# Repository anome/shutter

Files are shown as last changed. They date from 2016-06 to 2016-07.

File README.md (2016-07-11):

# SHUTTER

This repository contains all the files necessary to build your own radio shutter.
- The pcb folder contains the gerberfiles that you can send to any PCB factory.
- The laser folder contains the laser cutting files for 4 and 6 mm box.
- The code folder containsthe Arduino and PlatformIO projects to upload the code on the board

There is also an assembly guide explaining how to assemble all this.

## License

Those files are released under the CC-BY-NC license. More infos in the LICENSE.txt file.

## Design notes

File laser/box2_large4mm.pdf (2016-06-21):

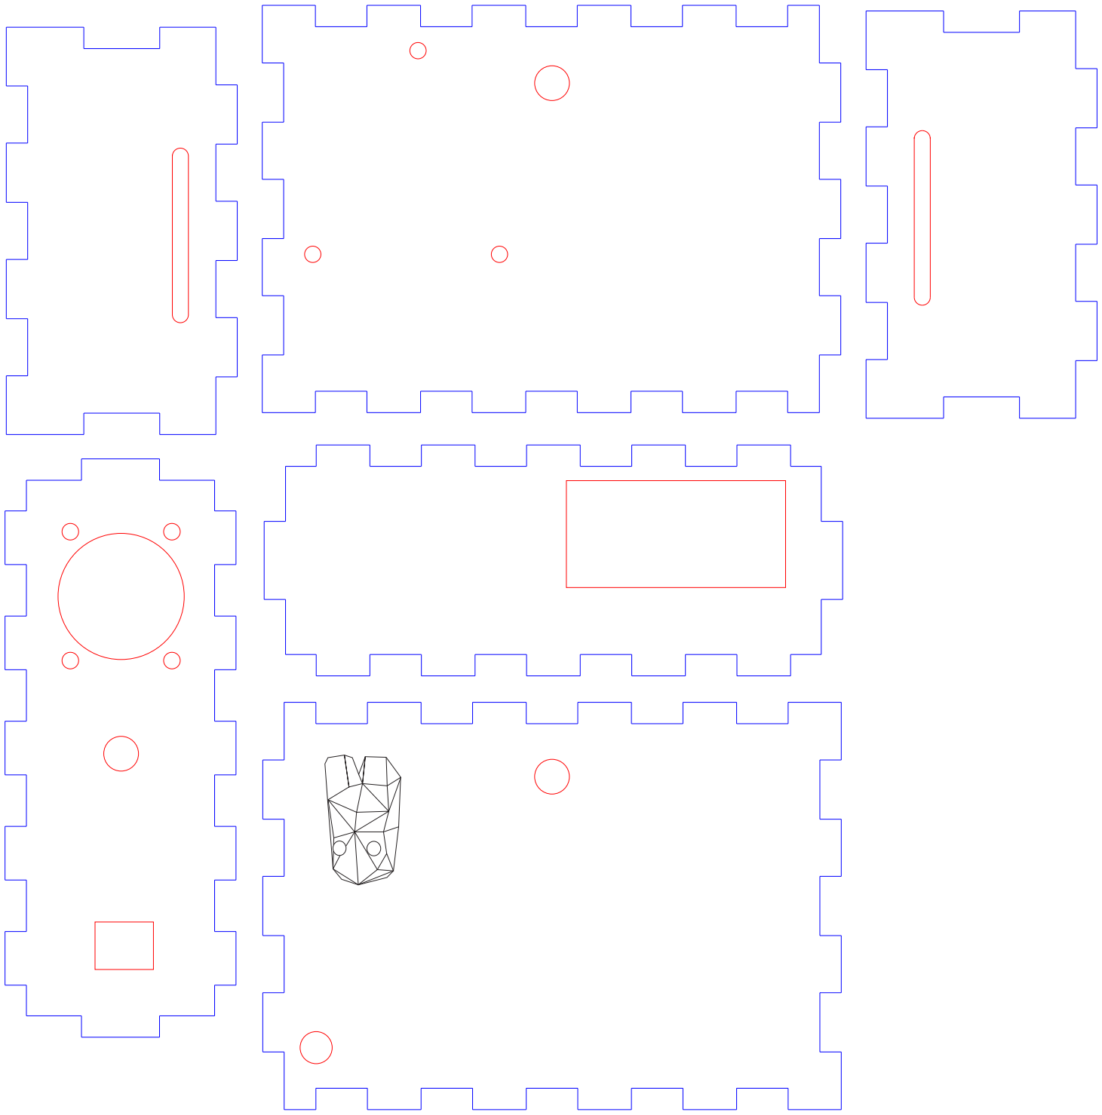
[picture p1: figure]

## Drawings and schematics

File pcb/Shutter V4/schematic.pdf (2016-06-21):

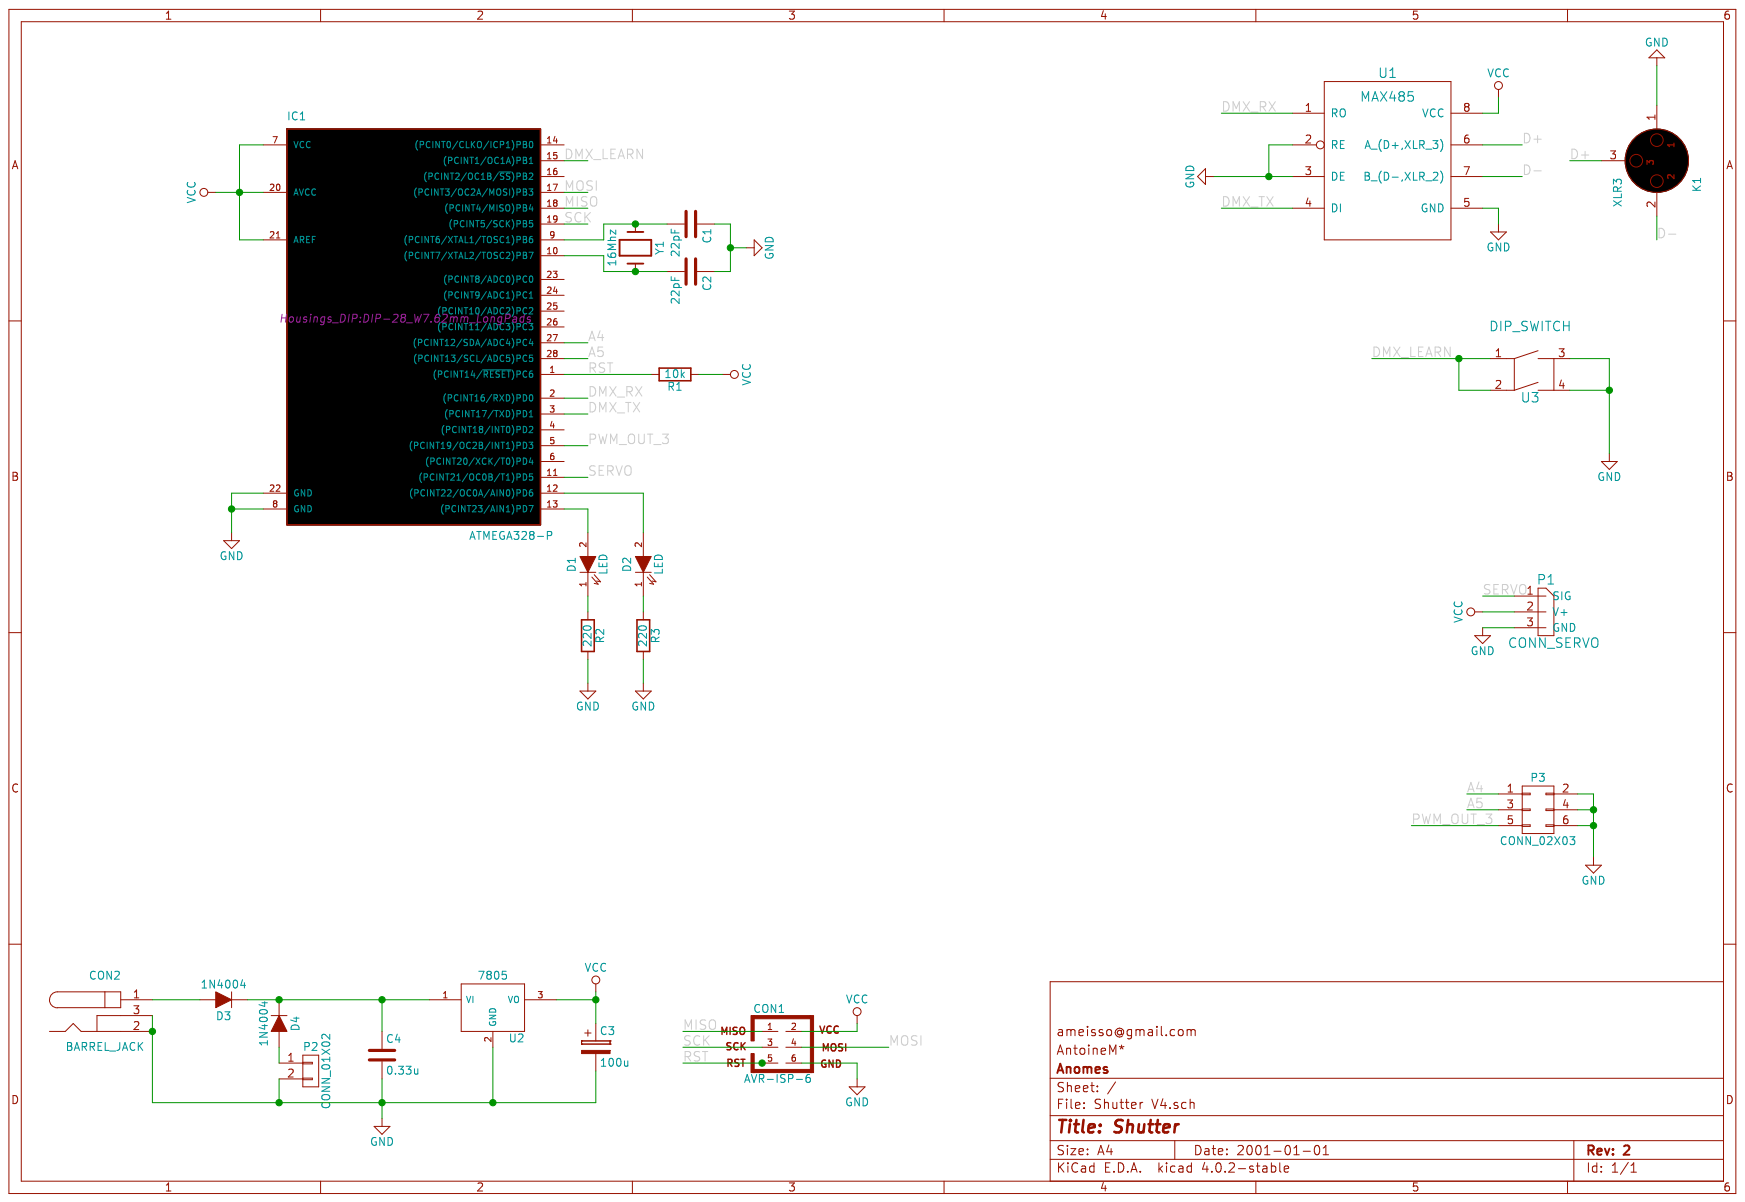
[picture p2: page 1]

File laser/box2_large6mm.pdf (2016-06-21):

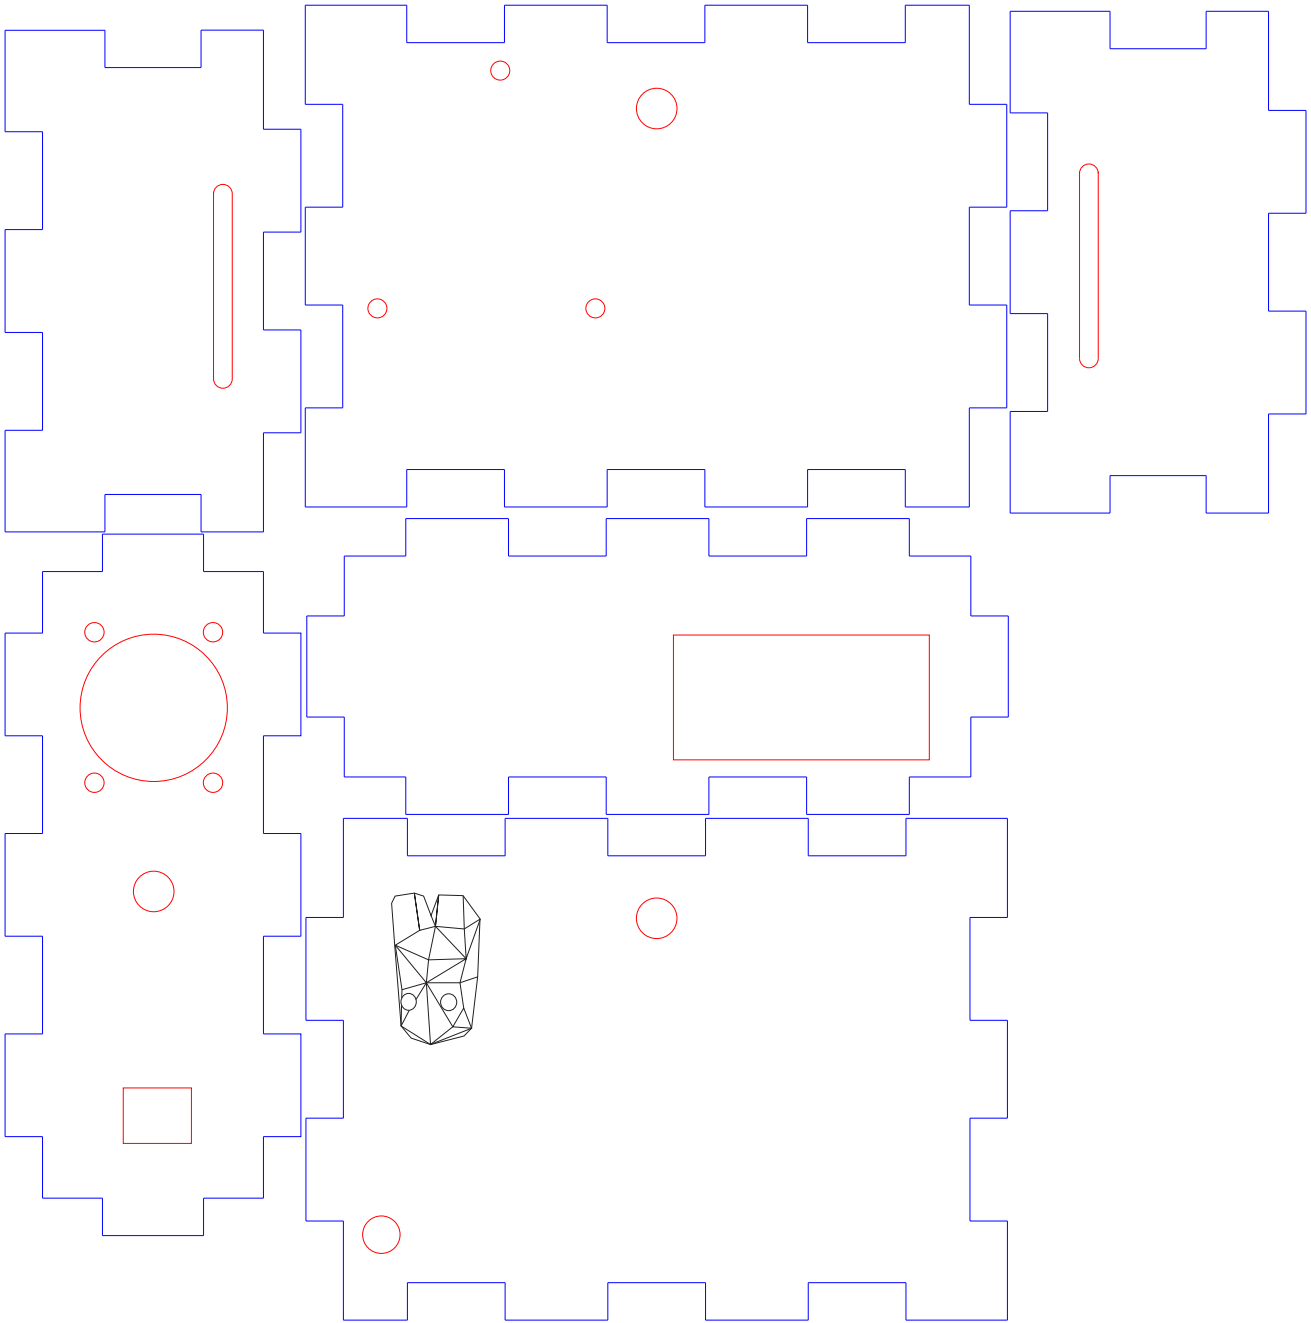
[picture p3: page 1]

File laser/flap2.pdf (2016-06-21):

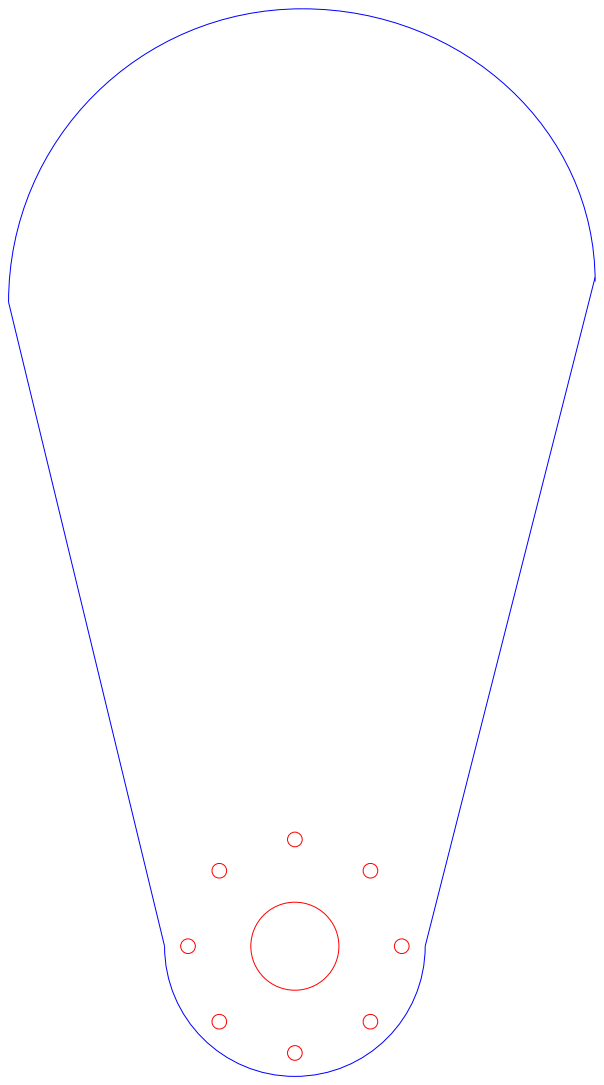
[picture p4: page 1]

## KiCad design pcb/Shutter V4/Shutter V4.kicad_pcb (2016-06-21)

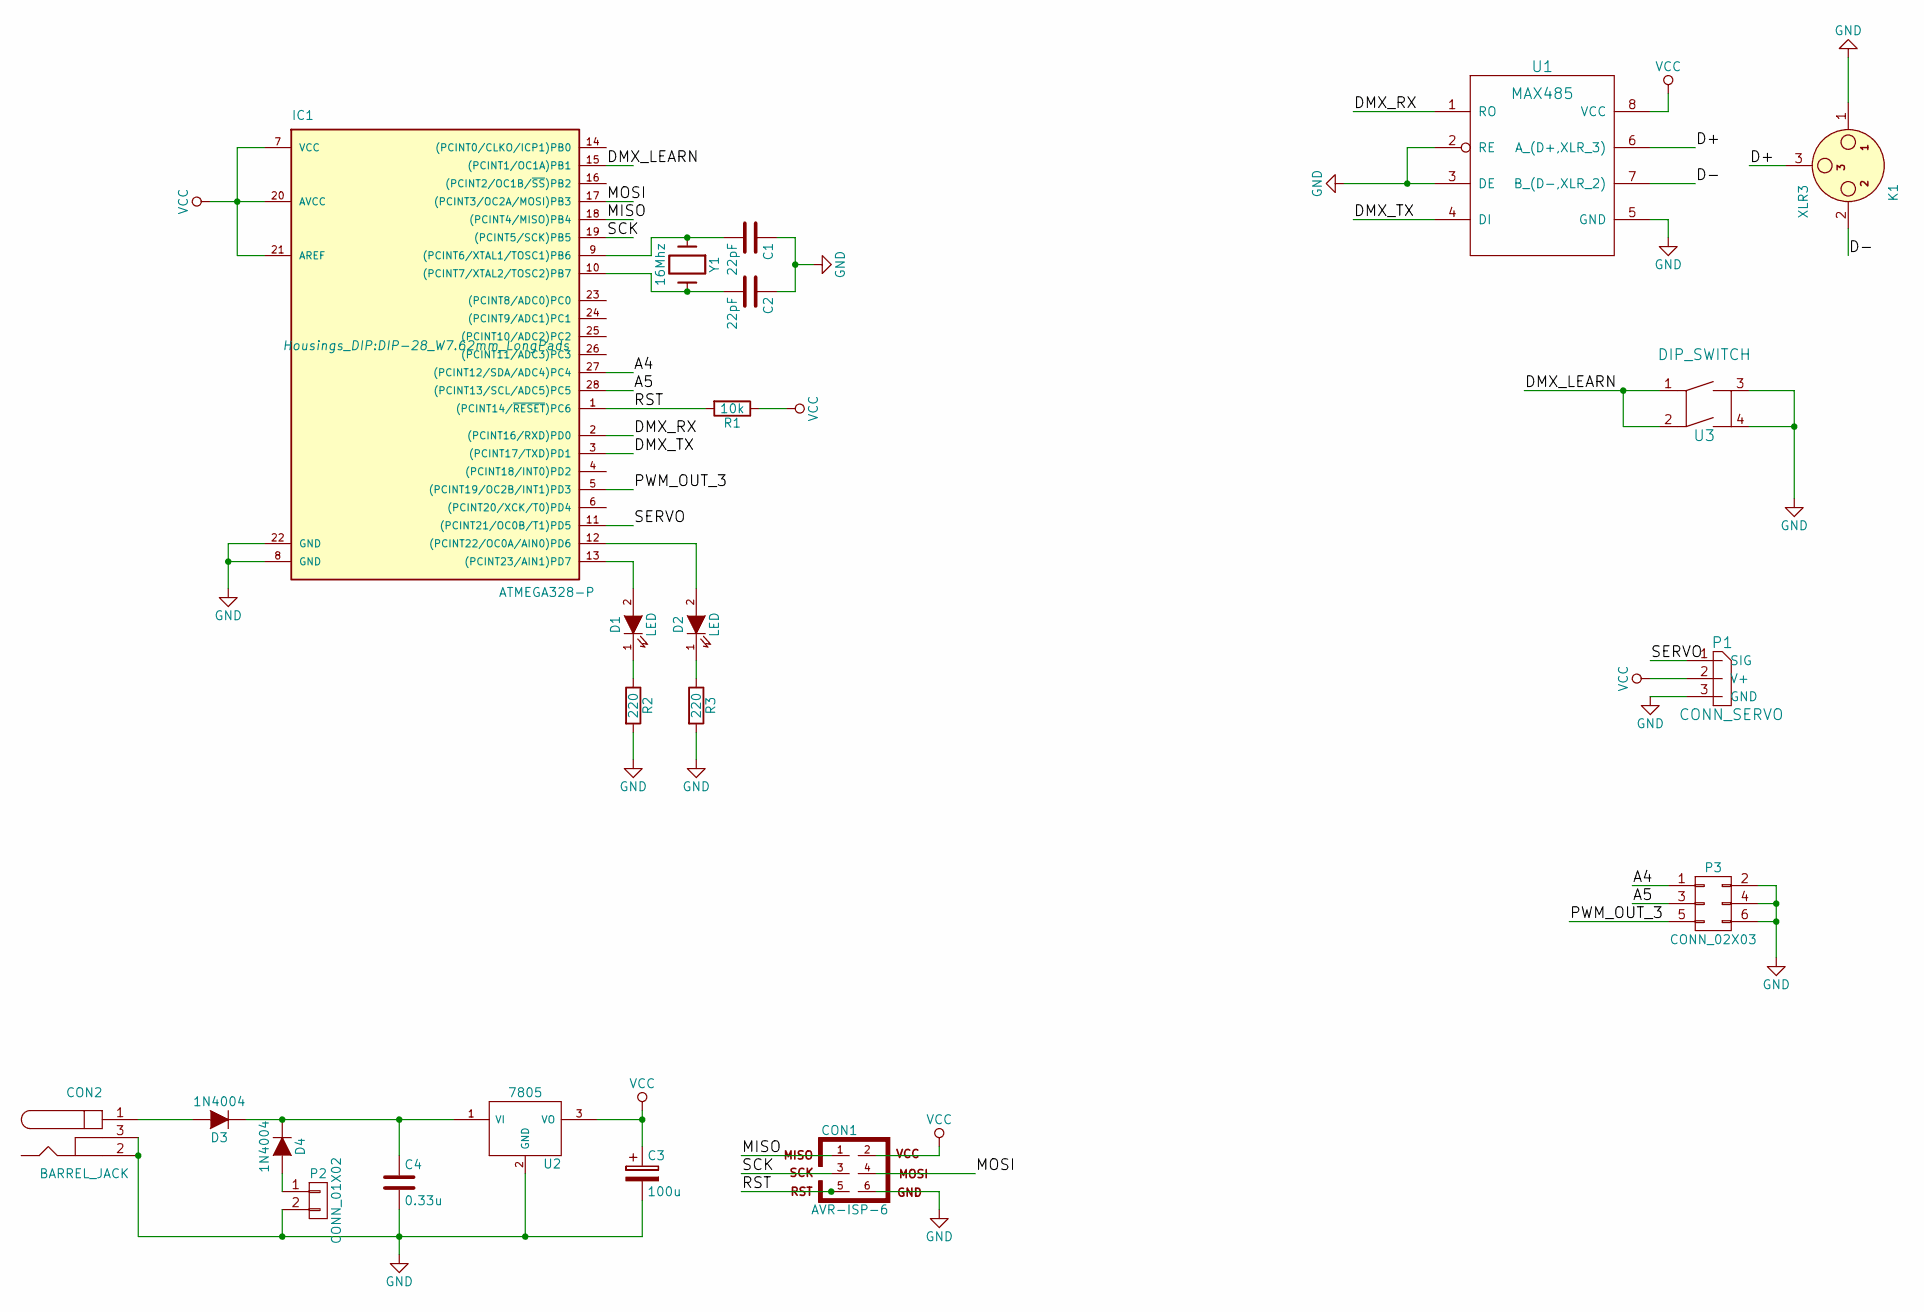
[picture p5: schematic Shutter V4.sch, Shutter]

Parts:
C1, C2: 22pF; C_Disc_D3_P2.5
C3: 100u; CP_VERT_6.3
C4: 0.33u; C_Rect_L7_W3.5_P5
CON1: AVR-ISP-6; CONN_ISP_6
CON2: BARREL_JACK; JACK_ALIM
D1, D2: LED; LED-5MM
D3, D4: 1N4004; Diode_DO-41_SOD81_Horizontal_RM10
IC1: ATMEGA328-P; DIP-28_W7.62mm_LongPads
K1: XLR3; CONN_075_3
P1: CONN_SERVO
P2: CONN_01X02; Pin_Header_Straight_1x02
P3: CONN_02X03; Pin_Header_Straight_2x03
R1: 10k; Resistor_Horizontal_RM10mm
R2, R3: 220; Resistor_Horizontal_RM10mm
U1: MAX485; DIP-8_W7.62mm
U2: 7805; TO220_HORYZ
U3: DIP_SWITCH; SW_TH_Tactile_Omron_B3F-10xx
Y1: 16Mhz; Crystal_HC49-U_Vertical

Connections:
/A4: IC1.27 ((PCINT12/SDA/ADC4)PC4), P3.1
/A5: IC1.28 ((PCINT13/SCL/ADC5)PC5), P3.3
/D+: K1.3, U1.6 (A_(D+,XLR_3))
/D-: K1.2, U1.7 (B_(D-,XLR_2))
/DMX_LEARN: IC1.15 ((PCINT1/OC1A)PB1), U3.1, U3.2
/DMX_RX: IC1.2 ((PCINT16/RXD)PD0), U1.1 (RO)
/DMX_TX: IC1.3 ((PCINT17/TXD)PD1), U1.4 (DI)
/MISO: CON1.1, IC1.18 ((PCINT4/MISO)PB4)
/MOSI: CON1.4, IC1.17 ((PCINT3/OC2A/MOSI)PB3)
/PWM_OUT_3: IC1.5 ((PCINT19/OC2B/INT1)PD3), P3.5
/RST: CON1.5, IC1.1 ((PCINT14/~RESET~)PC6), R1.2
/SCK: CON1.3, IC1.19 ((PCINT5/SCK)PB5)
/SERVO: IC1.11 ((PCINT21/OC0B/T1)PD5), P1.1 (SIG)
GND: C1.1, C2.1, C3.2, C4.2, CON1.6, CON2.2, CON2.3, IC1.8 (GND), IC1.22 (GND), K1.1, P1.3 (GND), P2.2, P3.2, P3.4, P3.6, R2.2, R3.2, U1.2 (RE), U1.3 (DE), U1.5 (GND), U2.2 (GND), U3.3, U3.4
unnamed: C1.2, IC1.9 ((PCINT6/XTAL1/TOSC1)PB6), Y1.1
unnamed: C2.2, IC1.10 ((PCINT7/XTAL2/TOSC2)PB7), Y1.2
unnamed: C4.1, D3.1 (K), D4.1 (K), U2.1 (VI)
unnamed: CON2.1, D3.2 (A)
unnamed: D1.1 (K), R2.1
unnamed: D1.2 (A), IC1.13 ((PCINT23/AIN1)PD7)
unnamed: D2.1 (K), R3.1
unnamed: D2.2 (A), IC1.12 ((PCINT22/OC0A/AIN0)PD6)
unnamed: D4.2 (A), P2.1
VCC: C3.1, CON1.2, IC1.7 (VCC), IC1.20 (AVCC), IC1.21 (AREF), P1.2 (V+), R1.1, U1.8 (VCC), U2.3 (VO)

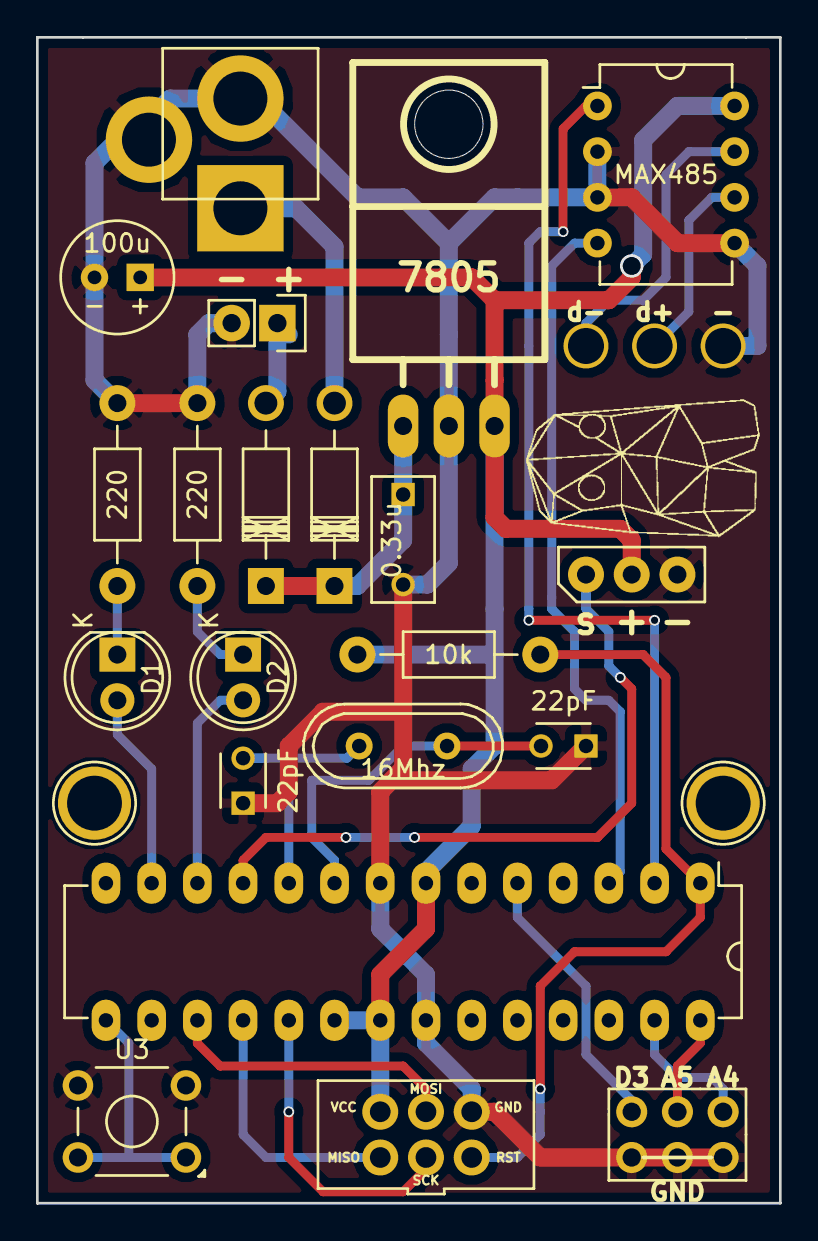
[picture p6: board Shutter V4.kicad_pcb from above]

Board: 2 copper layers, 41.3 x 64.8 mm, 23 parts (0 on the bottom side), 24 nets.

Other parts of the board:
LOGO: LOGO

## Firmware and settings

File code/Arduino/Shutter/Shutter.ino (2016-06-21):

#include <DMXSerial.h>
#include <EEPROM.h>
#include <Servo.h>

#define SHUTTER_HIGH 90
#define SHUTTER_LOW 0
#define SERVO_PIN 5
#define MANUAL_MODE_BUTTON A4
#define SIGNAL_LED 7
#define PWM_SIGNAL_LED 6
#define LEARN_DMX_BUTTON_PIN 9
#define DMX_EEPROM_ADDRESS 0

Servo servo;
bool lastDMXState = false;
bool lastManualState = false;
int lastServo = SHUTTER_LOW;
long lastMove = -1001;


void setup()
{
  pinMode(SIGNAL_LED, OUTPUT);
  pinMode(PWM_SIGNAL_LED, OUTPUT);
  pinMode(MANUAL_MODE_BUTTON, INPUT_PULLUP);
  pinMode(LEARN_DMX_BUTTON_PIN, INPUT_PULLUP);

  DMXSerial.init(DMXReceiver);
  servo.attach(SERVO_PIN);
  fastBlink();
  delay(1000);
}

void loop()
{
  updateLearnDMX();
  bool currentDMXState = getDMXState();
  bool currentManualState = getManualState();
  if ( currentDMXState != lastDMXState )
  {
    lastDMXState = currentDMXState;
    updateShutter( lastDMXState );
  }
  else if ( currentManualState != lastManualState )
  {
    lastManualState = currentManualState;
    updateShutter( lastManualState );
  }
  else
  {
    updateSleepMode();
  }
}

void updateLearnDMX()
{
  if ( ! digitalRead(LEARN_DMX_BUTTON_PIN) )
  {
    for (int i = 0 ; i < 512 ; i++)
    {
      if (DMXSerial.read(i) != 0)
      {
        EEPROM.write(DMX_EEPROM_ADDRESS, i & B11111111 );
        EEPROM.write(DMX_EEPROM_ADDRESS + 1, i  >> 8 & B11111111 );
        blink(3);
      }
    }
  }
}

bool getDMXState()
{
  unsigned long lastPacket = DMXSerial.noDataSince();
  if (lastPacket < 1000 )
  {
    int address = EEPROM.read(DMX_EEPROM_ADDRESS);
    address += EEPROM.read(DMX_EEPROM_ADDRESS + 1) << 8;
    int dmxValue = DMXSerial.read(address);
    analogWrite(PWM_SIGNAL_LED, dmxValue);
    if (dmxValue > 127)
    {
      return true;
    }
    else
    {
      return false;
    }
  }
  else
  {
    fastBlink();
  }
}

bool getManualState()
{
  return digitalRead( MANUAL_MODE_BUTTON );
}

void updateShutter(bool state)
{
  if ( state == true )
  {
    openShutter();
  }
  else
  {
    closeShutter();
  }
  lastMove = millis();
}

void updateSleepMode()
{
  if ( millis() - lastMove > 1000 )
  {
    servo.detach();
  }
}

void openShutter()
{
  if (lastServo != SHUTTER_HIGH)
  {
    servo.attach(SERVO_PIN);
    servo.write(SHUTTER_HIGH);
    lastServo = SHUTTER_HIGH;
  }
}

void closeShutter()
{
  if (lastServo != SHUTTER_LOW)
  {
    servo.attach(SERVO_PIN);
    servo.write(SHUTTER_LOW);
    lastServo = SHUTTER_LOW;
  }
}

void blink(int occurence)
{
  for (int i = 0 ; i < occurence ; i++)
  {
    digitalWrite(SIGNAL_LED, HIGH);
    digitalWrite(PWM_SIGNAL_LED, HIGH);
    delay(70);
    digitalWrite(SIGNAL_LED, LOW);
    digitalWrite(PWM_SIGNAL_LED, LOW);
    delay(300);
  }
}

void fastBlink()
{
  digitalWrite(SIGNAL_LED, HIGH);
  delay(70);
  digitalWrite(SIGNAL_LED, LOW);
  delay(50);
  digitalWrite(SIGNAL_LED, HIGH);
  delay(70);
  digitalWrite(SIGNAL_LED, LOW);
  delay(300);
}

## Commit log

2016-06-22 New : Mounting guide
2016-06-23 Fix : mounting guide update.
